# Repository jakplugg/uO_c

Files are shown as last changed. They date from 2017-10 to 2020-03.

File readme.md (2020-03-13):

# &#956;O_c 

### 8hp version of ornament and crime polymorphic CV generator by MXMXMX.

#### PCB redesign by J. Matheson. it works with the same firmware.

[Ornament and Crime project and manual, etc](http://ornament-and-cri.me/)

[Google sheets BOM](https://docs.google.com/spreadsheets/d/1SvdETid8HxN2XbK2KEajgjNHrxeO7aFor3uBw_pJ6no/edit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)

Note about the panel: there are 2 different hole spacing for the displays, Adafruit or ones made from the adafruit gerbers will fit the FPD panel in the panel folder. chinese ones from ebay, amazon, alliexpress, etc have a different hole spacing (see the pdf for oval holes used on PCB-panel) the PCB also has oval holes to support both displays.

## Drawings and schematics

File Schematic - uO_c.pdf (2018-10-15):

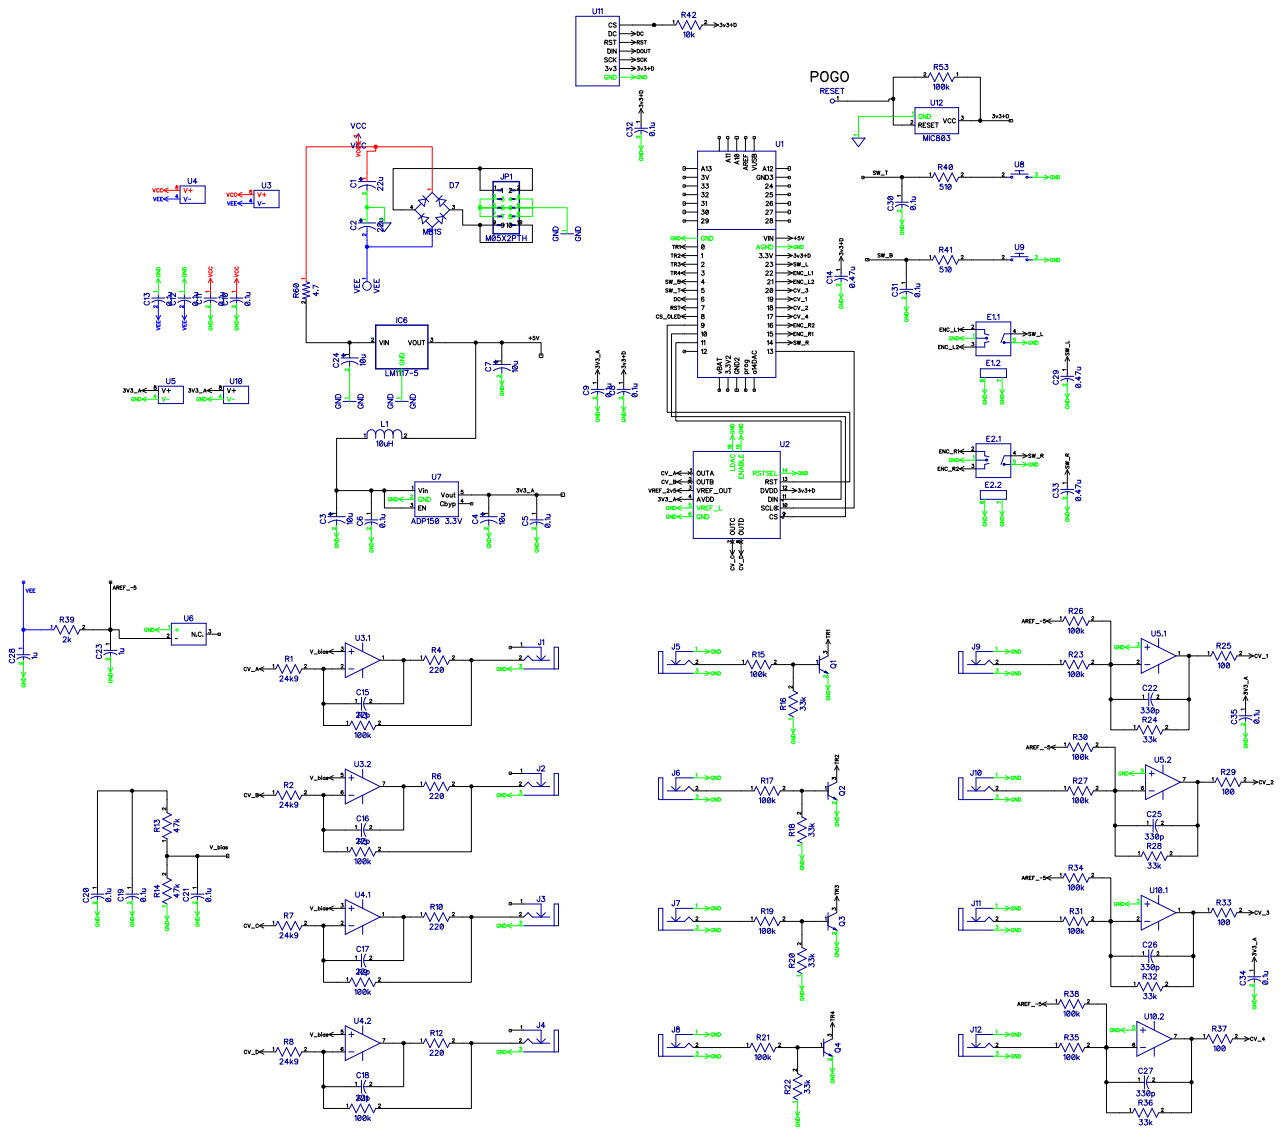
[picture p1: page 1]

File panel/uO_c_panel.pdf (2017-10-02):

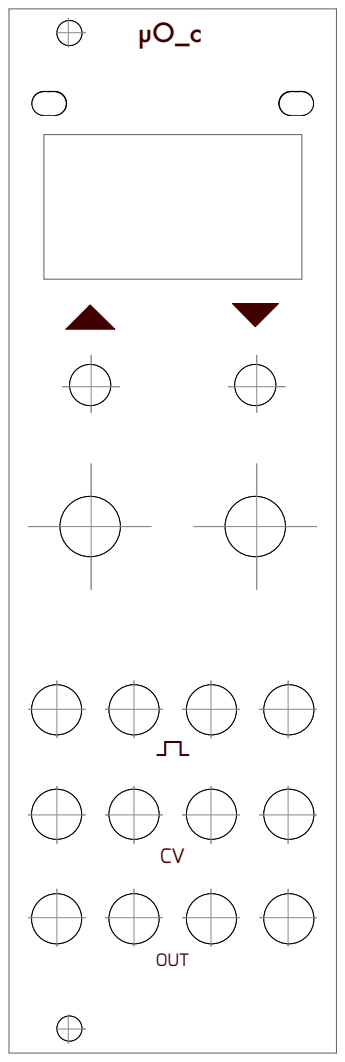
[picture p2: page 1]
OUT

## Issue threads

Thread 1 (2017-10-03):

CC-NC-BY-SA requires that the licensing be explicitly stated

timchurches, 2017-10-03:
The CC-BY-NC-SA and CC-BY-SA licensing of the O&C schematics and Gerbers respectively requires that derived schematics and Gerbers/layout files also be **explicitly** licensed in the same way, with appropriate attribution to satisfy the BY clauses of the license. I don't think it is enough just to say "see the Ornament & Crime web site". Please see the Creative Commons notes on attribution at https://wiki.creativecommons.org/wiki/Best_practices_for_attribution and these useful notes: https://www.newmediarights.org/guide/how_to/creative_commons/best_practices_creative_commons_attributions and this guide: http://creativecommons.org.au/materials/attribution.pdf

However, you should check with mxmxmx who holds the copyright on the O&C design to see what his wishes are regarding this, if you have not already done so.

jakplugg, 2017-10-03:
of course you are right, I am just trying to sort out the proper wording

timchurches, 2017-10-03:
OK, no worries. It’s arguable that your uO&C Gerbers (and the schematic and PCB layout files) should also be CC-BY-NC-SA licensed, unless Max has indicated otherwise, because they are derived from the CC-BY-NC-SA-licensed  O&C schematic, although that  is relying largely on moral rights because circuits per se are not copyrightable (but if moral rights to circuit designs are ignored, it’s a Blue Lantern free-for-all, which is bad for everyone). I recommend CC-BY-SA-NC licensing of the Gerbers and design files anyway, based on the massive organised-in-secret group-buys that occurred with the O&C (and Mutable, and other) Gerber or Eagle files released under a CC-BY-SA licence. The NC clause is unenforceable but at least it sends the message: if you want to sell this stuff, talk to the designers first.

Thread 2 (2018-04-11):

Paste Layer Gerbers

cdd3, 2018-04-11:
Would it be possible to publish the cream layer gerbers for making stencils?

jakplugg, 2018-04-14:
Sorry, but the diptrace file has had minor tweaks since then, so they would be wrong, hopefully some time next week ill release the new uo_c version (with supervisor teensy boot option), all the newer gerbers i upload have the paste layer.

cdd3, 2018-04-14:
Awesome, Thanks!

wardour, 2018-05-10:
Just wanted to jump on this, and say I'm looking forward to the new design with paste file available.

jakplugg, 2018-06-17:
so sorry i took so long with that, "put on google drive" does not equal uploaded to github!

cdd3, 2018-08-04:
Thanks so much. Really appreciate the work you've been up to!

Closed 2018-08-04.

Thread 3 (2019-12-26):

Differences between 6_9_17 and 25 janv 18

dimduj, 2019-12-26:
Hi !

What is the difference between thoses two versions ? are both working or only the 25_jav_18 ?
Wich do you recommand ?
Regards,

Dimitri

dimduj, 2019-12-26:
I respond to myself:

Found on muffwiggler:
https://muffwiggler.com/forum/viewtopic.php?f=17&t=189224&start=100

>
n0rd wrote:

What is the difference between v1.0 and v1.1 uO&C PCBs? (and how can I tell which version a PCB is? There doesn't seem to be a version number anywhere).

1.1 has U12 (under the teensy socket, upper left hand corner)

the 1.1 boards have the ruggedized power so the devices dont freeze on crappy PSUs. They need 3 extra parts: MIC803 votlage supervisor, 100K resistor, and a pogo pin on the front to connect to the reset pad of the teensy which is just a pad on the back of the teensy

dimduj, 2020-01-28:
Hi @jakplugg

I ce ordered  the 6-9-17 version 🙃...
Is this older version okay or won’t work with the BOM published on the current readme ( I see a there seems to be an issue with dip trace #2 but I m not sur it impact the gerber and pcb build or only the stencil generation)

Any help will be appreciate !

Cheers !

jakplugg, 2020-01-28:
If i remember, the main difference is the addition of the optional
supervisor ic, it's resistor, and the hole for a pogo pin. it is only
needed if the power supply comes up slow and the teensy fails to start
sometimes. some other components were moved to make it fit, so a
stencil made for this version would not work on older boards.

On 1/27/20, dimduj <notifications@github.com> wrote:
> Hi @jakplugg

>

> I ce ordered  the 6-9-17 version 🙃...

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

>

> Any help will be appreciate !

>

> Cheers !

>

> --

> You are receiving this because you were mentioned.

> Reply to this email directly or view it on GitHub:

> https://github.com/jakplugg/uO_c/issues/3#issuecomment-579031158

dimduj, 2020-02-08:
thx for your time/answer.

I've built two uoc using  v 6_9_17 and the BOM of the readme

I've the same issue on two:
During the calibration of CV output I've only 0.3v (not 1V) increment on each step on CV output.... but I've no idea what it could be . I double check each solder join and each resistor value but I can find any misplaced element ...

I assume this is not a mechanical problem since the error is the same on the two units and the rest seems to work as it should.

I' will probably try to looking for help on MW.

rbtatklik, 2020-03-04:
Just a heads up from the BOM on Github and the one listed on your link to MW above. The transistor - 512-MMBT3904 is not currently available and it has been suggested to replace it with 863-MMBT3904LT1G. Please confirm as my build is awaiting these parts.

Also the MIC803 spec'd in some of the BOMs is also out of stock and a suggested replacement is 998-MIC803-30D2VM3TR. Again requesting confirmation.

Thanks,

Rob T

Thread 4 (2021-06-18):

High Voltages on outputs

Ryanb369, 2021-06-18:
Just got done building the 6_9_17 board. Everything is working except i am getting +-11v coming out of the outputs when i try calibrating and calibration is very slow if not moving at all. I've tested power on the regulators, the DAC, as well as the V bias. The weird part on the v bias is that it is showing 1 v on U3 and u4. Any help would be much appreciated as i am quite stumped at this point.

jakplugg, 2021-07-10:
I think your output op amps might not be getting their negative rail power or something else in the analog realm.

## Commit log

2017-10-02 gerbers and schematics
    [uO_c.GBL, uO_c.GBO, uO_c.GBS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]
2017-10-02 add link to bOM
2017-10-02 link to bom
2017-10-02 removed wrong panel gerbers
    [Adafruit_1.3_128x64_OLED.brd, Adafruit_1.3_128x64_OLED.sch]
2017-10-19 added display gerbers
2017-10-26 fixed reverse side silkscreen on PCBpanel
    channel numbers were reversed on PCBpanel.
    moved panel gerbers to panel folder.
    [uO_c_panel.GBL, uO_c_panel.GBO, uO_c_panel.GBS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]
2018-06-17 1.1 gerbers
    new version with optional supervisor
    [uO_c1.1.GBL, uO_c1.1.GBO, uO_c1.1.GBP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]
2020-03-13 update BOM
